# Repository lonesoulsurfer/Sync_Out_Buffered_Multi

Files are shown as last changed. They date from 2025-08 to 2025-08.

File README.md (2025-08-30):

Buffered Multiple for Modular Synths - Powered by Arduino

thumbnail_IMG_1372

Vid of the Sync in action
https://youtu.be/81T7WBMwU_8

Step by step guide (Instructables)
https://www.instructables.com/Buffered-Multiple-for-Modular-Synths-Powered-by-Ar/

Takes one sync input signal and produces six individually configurable outputs
 - Shows current BPM on OLED display
 - Each output can be configured with:
      - Normal sync (1:1)
      - Clock division (1/2, 1/4, 1/8)
      - Three groove patterns:
          - GS: Swing (delays off-beats by fixed amount)
          - GF: Shuffle (creates triplet-based rhythm)
          - GH: Humanize (adds random timing variations)

Groove Implementation 

Swing (GS) = consistent delayed off-beats
 -Delays off-beats by shifting timing up to 66% through beat
- Very classic swing feel at 50-75% intensities
- Clean implementation with consistent timing

Shuffle (GF) = polyrhythmic feel with specific timing ratios
- Creates 2-against-3 feel using weighted offset timing
- Distinct from swing - pushes toward triplet territory
- At 75%, approaches dotted 8th feeling (funkier)

Humanize (GH) = unpredictable variations
- Adds random timing variation around off-beats
- Much stronger randomization (up to 40% of beat)
- More chaotic/organic feel compared to others

The implementation provides good sonic variety between the modes. Each mode serves a distinct musical purpose, and the intensity levels (50%/75%) allow meaningful adjustment.
The two intensity levels (50% and 75%) offer enough adjustability without overcomplicating the interface. This gives users six distinct groove feels to choose from (three types × two intensities), which is a good balance for this type of device.

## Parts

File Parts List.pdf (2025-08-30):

Part Type Value Qty | Image | Link | Notes
Capacitor Polypropylene 104J 100nf 1 | | Link (https://vi.aliexpress.com/w/wholesale-capacitor-100nf.html?spm=a2g0o.productlist.search.0)
Capacitor Polarized 100uf 1 ESR | | Link (https://vi.aliexpress.com/w/wholesale-capacitor-100uf-.html?spm=a2g0o.productlist.search.0) | I like to use high frequency, low noise capacitors
Momentary (PN SKRCADD010) 3 Switch On/Off Toggle Switch Through Hole version 1 | | Link (https://www.aliexpress.com/w/wholesale-SKRCADD010.html?spm=a2g0o.productlist.search.0) Link (https://vi.aliexpress.com/item/1005001510219617.html) | Make sure that the pins on the switch are Stich pins and are able to go through the holes in the PCB
Female Header Pin Socket 15 Pin 2 | | Link (https://vi.aliexpress.com/w/wholesale-Single-Row-Female-2.54MM-Spacing-Pin.html) | These are used to hold the Arduino into place. You could solder the Arduino onto the PCB but be careful of shorts that may happen against the components on the other side
Arduino Nano 3 1 | | Link (https://vi.aliexpress.com/w/wholesale-arduino-nano.html?spm=a2g0o.detail.search.0)
Audio Socket 3.5mm (PN - PJ-301M) 7 | | Link (https://vi.aliexpress.com/item/1005005352992401.html?scm_id=1007.40050.354490.0&scm-url=1007.40050.354490.0)
Mini JST Connector and wire 2 Pin 1 | | Link (https://vi.aliexpress.com/item/1005005939956886.html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) | This is used to either power the PCB or to test it. If you are going with the 9v battery then you could leave this
LED 3mm (any colour) 1 | | Link (https://vi.aliexpress.com/w/wholesale-3mm-led-assorted.html?spm=a2g0o.productlist.search.0)
OLED Display I2C, 4 Pin 1 128X64 | | Link (https://www.aliexpress.com/w/wholesale-oled-128-x-64.html?spm=a2g0o.home.search.0)
220R Resistors Metal Film 1% 2.2K | 6 1 | | Link (https://vi.aliexpress.com/w/wholesale-resistor-metal-film.html?spm=a2g0o.productlist.search.0)

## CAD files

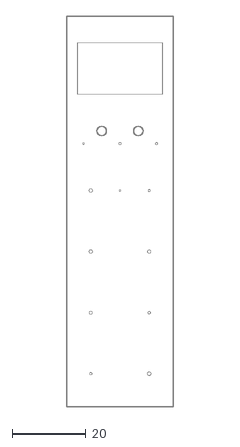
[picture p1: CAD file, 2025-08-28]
Front Panel Design/Sync Out - PCB.dxf
28.8 x 105.5

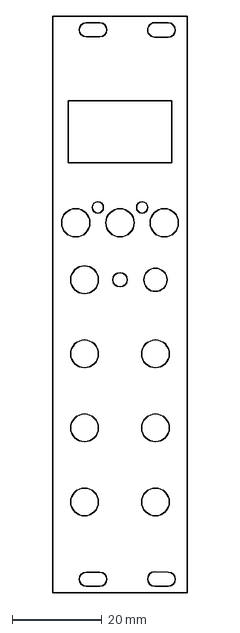
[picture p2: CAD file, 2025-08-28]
Front Panel Design/Sync Out - Fusion.dxf
30.0 x 128.5 mm

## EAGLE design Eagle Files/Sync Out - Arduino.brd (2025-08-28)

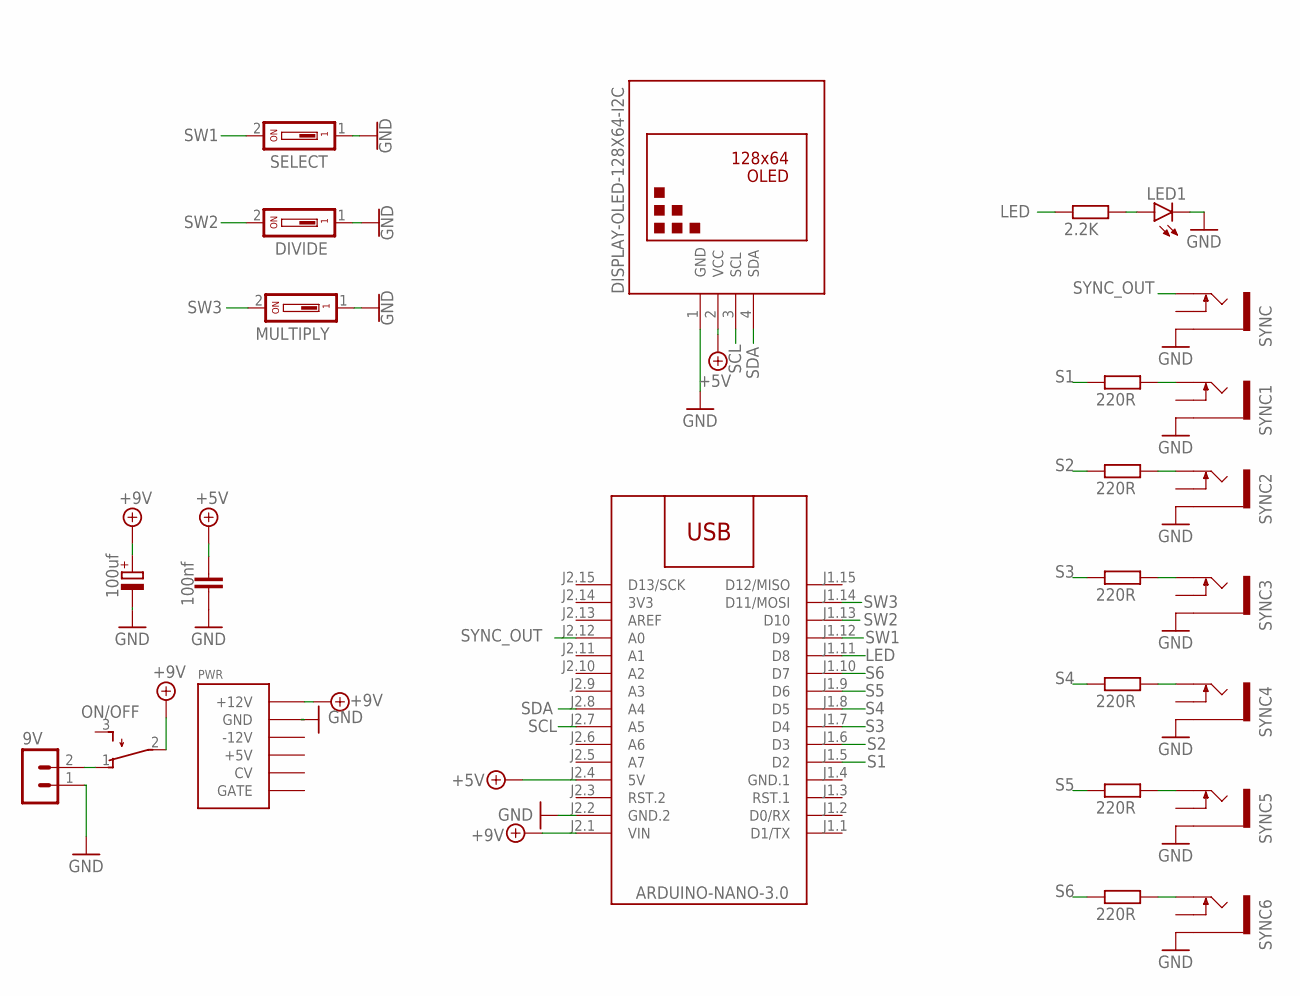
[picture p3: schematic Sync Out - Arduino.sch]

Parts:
9V: B2B-PH-K-S
C1: 100nf; C050-024X044
C3: 100uf; E2-5
DIVIDE: DS01; DS-01
LED1: LED3MM
M1: ARDUINO-NANO-3.0
MULTIPLY: DS01; DS-01
ON/OFF: TL32PO; TL3XPO
PWR: POWER; POWER_16
R1, R2, R3, R4, R5, R6: 220R; 0207/10
R7: 2.2K; 0207/10
SELECT: DS01; DS-01
SYNC, SYNC1, SYNC2, SYNC3, SYNC4, SYNC5, SYNC6: THONKICONNNEW; WQP-PJ301M-12_JACK
U$2: DISPLAY-OLED-128X64-I2C

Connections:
3V3: M1.J2.14 (3V3)
+5V: C1.1, M1.J2.4 (5V), U$2.2 (VCC)
+9V: C3.+, M1.J2.1 (VIN), ON/OFF.2, PWR.9 (+12V), PWR.10 (+12V)
GND: 9V.1, C1.2, C3.-, DIVIDE.1, LED1.K (C), M1.J2.2 (GND.2), MULTIPLY.1, PWR.3 (GND), PWR.4 (GND), PWR.5 (GND), PWR.6 (GND), PWR.7 (GND), PWR.8 (GND), SELECT.1, SYNC.P$3_SLEEVE (SLEEVE), SYNC1.P$3_SLEEVE (SLEEVE), SYNC2.P$3_SLEEVE (SLEEVE), SYNC3.P$3_SLEEVE (SLEEVE), SYNC4.P$3_SLEEVE (SLEEVE), SYNC5.P$3_SLEEVE (SLEEVE), SYNC6.P$3_SLEEVE (SLEEVE), U$2.1 (GND)
GND.1: M1.J1.4 (GND.1)
LED: M1.J1.11 (D8), R7.1
unnamed: LED1.A, R7.2
unnamed: 9V.2, ON/OFF.1 (O)
unnamed: R1.2, SYNC1.P$1_TIP (TIP)
unnamed: R2.2, SYNC2.P$1_TIP (TIP)
unnamed: R3.2, SYNC3.P$1_TIP (TIP)
unnamed: R4.2, SYNC4.P$1_TIP (TIP)
unnamed: R5.2, SYNC5.P$1_TIP (TIP)
unnamed: R6.2, SYNC6.P$1_TIP (TIP)
S1: M1.J1.5 (D2), R1.1
S2: M1.J1.6 (D3), R2.1
S3: M1.J1.7 (D4), R3.1
S4: M1.J1.8 (D5), R4.1
S5: M1.J1.9 (D6), R5.1
S6: M1.J1.10 (D7), R6.1
SCL: M1.J2.7 (A5), U$2.3 (SCL)
SDA: M1.J2.8 (A4), U$2.4 (SDA)
SW1: M1.J1.12 (D9), SELECT.2
SW2: DIVIDE.2, M1.J1.13 (D10)
SW3: M1.J1.14 (D11/MOSI), MULTIPLY.2
SYNC_OUT: M1.J2.12 (A0), SYNC.P$1_TIP (TIP)

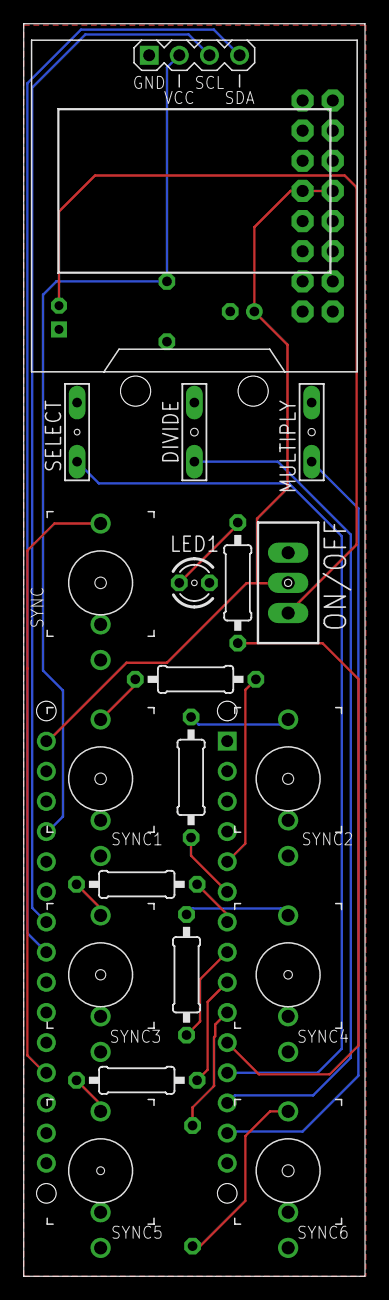
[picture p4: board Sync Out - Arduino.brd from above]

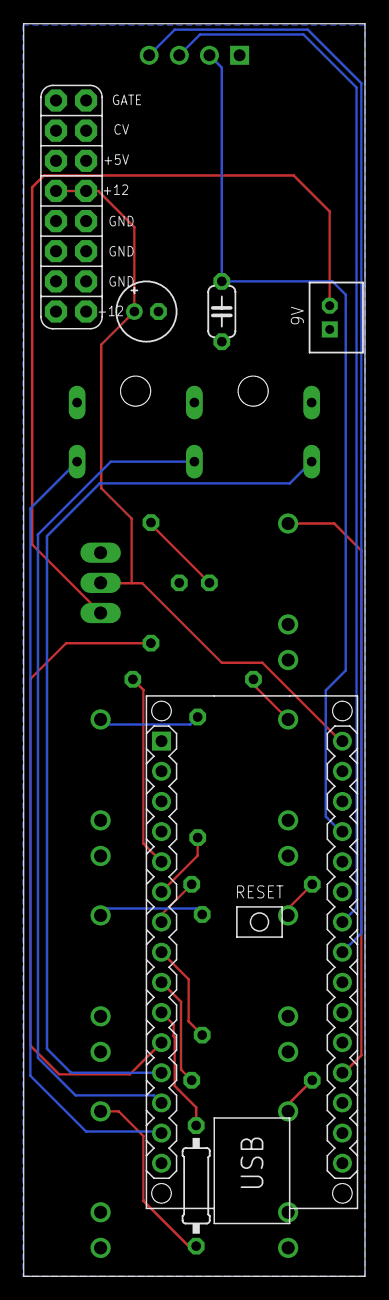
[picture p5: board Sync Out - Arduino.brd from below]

Board: 2 copper layers, 28.8 x 105.5 mm, 25 parts (6 on the bottom side), 24 nets.

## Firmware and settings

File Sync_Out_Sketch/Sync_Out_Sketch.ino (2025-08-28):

/* Synth Sync Signal Splitter with BPM display and clock division/groove
  Creates 6 buffered sync output signals from 1 input signal
  For Arduino Nano
*/

#include <Wire.h>
#include <Adafruit_GFX.h>
#include <Adafruit_SSD1306.h> // Display driver

#define SCREEN_WIDTH 128
#define SCREEN_HEIGHT 64
#define OLED_RESET -1
Adafruit_SSD1306 display(SCREEN_WIDTH, SCREEN_HEIGHT, &Wire, OLED_RESET);
// Constants for groove patterns
#define GROOVE_STRAIGHT 0    // No groove
#define GROOVE_SWING_8TH 1   // Standard swing feel
#define GROOVE_SHUFFLE 2     // Triplet-based shuffle
#define GROOVE_HUMANIZE 3    // Random humanization

// Groove settings (-8 to -1 now represent groove patterns instead of multiplication)
int grooveAmount[] = {0, 0, 0, 0, 0, 0}; // Amount of groove (0-100%)
int grooveType[] = {GROOVE_STRAIGHT, GROOVE_STRAIGHT, GROOVE_STRAIGHT, GROOVE_STRAIGHT, GROOVE_STRAIGHT, GROOVE_STRAIGHT};

const int syncInPin = A0;    // Analog input pin for sync signal
const int syncOutPins[] = {2, 3, 4, 5, 6, 7}; // Six digital output pins
const int indicatorLED = 8;  // LED to indicate sync pulses
const unsigned long minPulseWidth = 30;  // Increased pulse width for better synth compatibility
const int threshold = 400;   // Adjusted for 2V input

// Button pins
const int selectButton = 9;  // Button to select which output to adjust
const int divideButton = 10; // Button to increase division
const int multiplyButton = 11; // Button to increase multiplication

// Button states
bool lastSelectState = HIGH;
bool lastDivideState = HIGH;
bool lastMultiplyState = HIGH;
unsigned long lastDebounceTime = 0;
unsigned long debounceDelay = 50; // Debounce time in ms

// Division/groove values
// Values < 0 represent groove mode (e.g., -1 = groove active)
// Values > 0 represent division (e.g., 2 = 1/2 speed)
// Value of 1 is normal speed
int clockRatios[] = {1, 1, 1, 1, 1, 1};
int selectedOutput = 0; // Currently selected output (0-5)

// Count pulses for each output
int pulseCounts[] = {0, 0, 0, 0, 0, 0};
// Output state trackers
bool outputStates[] = {false, false, false, false, false, false};

unsigned long lastPulseTime = 0;
unsigned long currentTime = 0;
unsigned long lastDisplayUpdate = 0;
unsigned long pulseStartTime[6] = {0}; // Track when each output was turned on
float bpm = 120; // Start with default value
bool showingBpm = false;
float lastValidBpm = 0;
unsigned long bpmStableTime = 0;
bool lastSyncState = false;
unsigned long lastPulseTimeout = 2000;
unsigned long lastSubdivisionTime[6] = {0}; // Track timing for each output
unsigned long lastStableBpm = 0; // Track when we last had a stable BPM
bool bpmDisplayStable = false; // Flag to indicate if BPM is stable

// BPM averaging
#define BPM_SAMPLES 3
unsigned long pulseTimes[BPM_SAMPLES];
int pulseIndex = 0;

void setup() {
  // Set all output pins
  for (int i = 0; i < 6; i++) {
    pinMode(syncOutPins[i], OUTPUT);
    digitalWrite(syncOutPins[i], LOW);
  }
  
  // Set button pins as inputs with pull-up resistors
  pinMode(selectButton, INPUT_PULLUP);
  pinMode(divideButton, INPUT_PULLUP);
  pinMode(multiplyButton, INPUT_PULLUP);
  
  pinMode(syncInPin, INPUT);
  pinMode(indicatorLED, OUTPUT);
  
  // Initialize OLED
  if(!display.begin(SSD1306_SWITCHCAPVCC, 0x3C)) {
    for(;;);
  }
  
  display.clearDisplay();
  display.setTextSize(2);
  display.setTextColor(SSD1306_WHITE);
  display.setCursor(20, 0);
  display.println("SYNC OUT");
  display.display();
  delay(1000);
  
  // Initialize pulse time array
  for (int i = 0; i < BPM_SAMPLES; i++) {
    pulseTimes[i] = 0;
  }
}

float calculateBPM() {
  // Calculate average duration between pulses
  unsigned long totalDuration = 0;
  int validSamples = 0;
  
  // Return early if we don't have valid samples
  if (pulseTimes[0] == 0) {
    return lastValidBpm > 0 ? lastValidBpm : 0;
  }
  
  for (int i = 0; i < BPM_SAMPLES-1; i++) {
    if (pulseTimes[i] > 0 && pulseTimes[i+1] > 0) {
      totalDuration += pulseTimes[i+1] - pulseTimes[i];
      validSamples++;
    }
  }
  
  if (validSamples > 0) {
    float avgDuration = (float)totalDuration / validSamples;
    return 60000.0 / avgDuration;
  }
  
  return 0;
}

void updateDisplay() {
  display.clearDisplay();
  display.setTextSize(1);
  display.setCursor(0, 0); 
  display.println("SYNC OUT");
  
  // Show BPM
  display.setTextSize(2);
  display.setCursor(0, 12); 
  
  // Only show a BPM if we've had pulses in the last 3 seconds
  if (currentTime - lastPulseTime < 3000) {
    // Only update lastValidBpm if bpm is not zero
    if (int(lastValidBpm) > 0) {
      display.print(int(lastValidBpm));
     }
 }
  else {
    display.print("---");
  }
  display.println(" BPM");
  
  // Add more space between BPM and clock divisions
  display.setCursor(0, 34);
  
  // Show clock divisions/groove
  display.setTextSize(1); // Back to size 1 (default size)
  
  display.setTextColor(SSD1306_WHITE);
  for (int i = 0; i < 6; i++) {
    display.print(i+1);
    display.print(":");
    
    if (clockRatios[i] < 0) {
      display.print("G");
      switch(grooveType[i]) {
       case GROOVE_SWING_8TH: display.print("S"); break;  // GS = Groove Swing
        case GROOVE_SHUFFLE: display.print("F"); break;    // GF = Groove Shuffle
        case GROOVE_HUMANIZE: display.print("H"); break;   // GH = Groove Humanize
      }
      display.print(grooveAmount[i]);
      display.print("%");
    } 
    else if (clockRatios[i] == 1) {
      display.print("1:1");
    } 
    else {
      display.print("1/");
      display.print(clockRatios[i]);
    }
    
    if (i == selectedOutput) {
      display.print("*"); // Mark selected output
    }
    
    display.print(" ");
    
    // New line every 3 outputs
    if (i == 2) {
      display.setCursor(0, 46);
    }
  }
  
  display.display();
}

void handleButtons() {
  // Read button states
  bool selectState = digitalRead(selectButton);
  bool divideState = digitalRead(divideButton);
  bool multiplyState = digitalRead(multiplyButton);
  
  // Handle select button (with debounce)
  if (selectState != lastSelectState && millis() - lastDebounceTime > debounceDelay) {
    lastDebounceTime = millis();
    if (selectState == LOW) { // Button pressed
      selectedOutput = (selectedOutput + 1) % 6;
      updateDisplay();
    }
    lastSelectState = selectState;
  }
  
  // Handle divide button (with debounce)
  if (divideState != lastDivideState && millis() - lastDebounceTime > debounceDelay) {
    lastDebounceTime = millis();
    if (divideState == LOW) { // Button pressed
      // Increase division (or decrease multiplication)
      if (clockRatios[selectedOutput] < 0) {
        // Currently in groove mode
        // Go to normal
        clockRatios[selectedOutput] = 1;
        grooveAmount[selectedOutput] = 0;
        grooveType[selectedOutput] = GROOVE_STRAIGHT;
      } else if (clockRatios[selectedOutput] == 1) {
        // Currently normal, switch to division
        clockRatios[selectedOutput] = 2; // Start at 1/2 speed
      } else {
        // Already in division mode
        clockRatios[selectedOutput] *= 2; // Double division (slower)
        if (clockRatios[selectedOutput] > 64) clockRatios[selectedOutput] = 64; // Max division 1/64
      }
      updateDisplay();
    }
    lastDivideState = divideState;
  }
  
  // Handle multiply button (with debounce)
  if (multiplyState != lastMultiplyState && millis() - lastDebounceTime > debounceDelay) {
    lastDebounceTime = millis();
    if (multiplyState == LOW) { // Button pressed
      // Increase multiplication (or decrease division)
      if (clockRatios[selectedOutput] > 1) {
        // Currently in division mode
        // If we're at 1/2, go straight to normal
        if (clockRatios[selectedOutput] == 2) {
          clockRatios[selectedOutput] = 1;
          grooveType[selectedOutput] = GROOVE_STRAIGHT;
        } else {
          clockRatios[selectedOutput] /= 2; // Move closer to 1 (faster)
        }
      } else if (clockRatios[selectedOutput] == 1) {
        // Currently normal, switch to groove mode
        clockRatios[selectedOutput] = -1; // Negative values = groove
        grooveType[selectedOutput] = GROOVE_SWING_8TH;
        grooveAmount[selectedOutput] = 50; // Start with 50% swing
      } else {
        // Already in groove mode, cycle through patterns
        // Skip GROOVE_STRAIGHT (0) in the cycle to avoid those "do nothing" modes
        if (grooveType[selectedOutput] == GROOVE_SWING_8TH) {
          grooveType[selectedOutput] = GROOVE_SHUFFLE;
        } else if (grooveType[selectedOutput] == GROOVE_SHUFFLE) {
          grooveType[selectedOutput] = GROOVE_HUMANIZE;
        } else { // GROOVE_HUMANIZE or any other
          // After cycle completes, return to SWING but with increased intensity
          grooveType[selectedOutput] = GROOVE_SWING_8TH;
          grooveAmount[selectedOutput] = min(grooveAmount[selectedOutput] + 25, 100);
          if (grooveAmount[selectedOutput] > 75) {
            clockRatios[selectedOutput] = 1; // Back to normal after max groove
          }
        }
      }
      updateDisplay();
    }
    lastMultiplyState = multiplyState;
  }
}

void handleGroove() {
  unsigned long currentTime = millis();
  
  for (int i = 0; i < 6; i++) {
    // Only process if in groove mode
    if (clockRatios[i] < 0) {
      // Skip if no recent pulses or BPM too low
      if (currentTime - lastPulseTime > 2000 || bpm < 30) continue;
      
      // Get beat duration
      unsigned long beatDuration = 60000 / bpm;
      
      // Only process for outputs not already high
      if (!outputStates[i]) {
        unsigned long timeSinceMainPulse = currentTime - lastSubdivisionTime[i];
         
        // Apply groove based on type
        switch (grooveType[i]) {
          case GROOVE_SWING_8TH:
            {
         // Calculate swing timing (move off-beat later based on amount)     
              // More dramatic swing effect: up to 66% of beat duration at max intensity
              unsigned long swingTime = beatDuration/2 + 
                                      (beatDuration/3 * grooveAmount[i]/100);              
               
            // Use a wider detection window (like in humanize mode)
              if (!outputStates[i] && timeSinceMainPulse >= (swingTime - 20) && 
                  timeSinceMainPulse <= (swingTime + 20)) {    // No randomization in swing mode - always consistent timing
                outputStates[i] = true;
                digitalWrite(syncOutPins[i], HIGH);
                pulseStartTime[i] = currentTime;       
              }
            }
            break;
            
          case GROOVE_SHUFFLE:
            // Triplet-based shuffle - create pulses at 1/3 and 2/3 points
            {
           // New approach: use 2-against-3 polyrhythm for shuffle feel
              // Only fire pulses on the downbeat and one weighted offset
               
              // Effective time since the last main pulse   
              unsigned long timeSinceMainPulse = currentTime - lastSubdivisionTime[i];
               
              // Ensure we're not past the next beat
              if (timeSinceMainPulse >= beatDuration) {
                break;
              }
               
              // Instead of triplets, use a weighted offset that feels like shuffle
              // At 100% intensity, this becomes close to a dotted 8th
              // Start with base offset (halfway through beat)
              unsigned long baseOffset = beatDuration / 2;
              
              // Adjust offset based on groove intensity (0-100%)
              // This creates a continuum between straight 8ths and dotted 8ths
              unsigned long adjustedOffset = baseOffset + 
                                           (baseOffset/3 * grooveAmount[i]/100);
                                           
              // Use a wide detection window for reliable triggering
              if (timeSinceMainPulse >= (adjustedOffset - 15) && 
                  timeSinceMainPulse <= (adjustedOffset + 15) && 
                  !outputStates[i]) {
                outputStates[i] = true;
                digitalWrite(syncOutPins[i], HIGH);
                pulseStartTime[i] = currentTime;
                
                 // Extra pulse width handled by handleClockDivision()
                // Avoid delays here to prevent timing issues
              }
             }                   
            break;
            
          case GROOVE_HUMANIZE:
            // Random timing variations around the off-beat
            if (beatDuration > 0) {
              // Create pulses at half-beat points with random variation
              unsigned long halfBeat = beatDuration / 2;  
              unsigned long timeSinceMainPulse = currentTime - lastPulseTime;
               // Much stronger humanize effect: up to 40% of beat at max intensity
               int variation = map(grooveAmount[i], 0, 100, 0, beatDuration*2/5);
              
              // Check if we're near the halfway point (with tolerance)
              if (!outputStates[i] && 
               timeSinceMainPulse >= (halfBeat - 20) && 
                   timeSinceMainPulse <= (halfBeat + 20)) {
                int randomOffset = random(-variation, variation);
                // Apply the random offset to make humanize more pronounced
                // Using a much shorter delay to avoid blocking
                delayMicroseconds(abs(randomOffset) * 100);
                outputStates[i] = true;
                digitalWrite(syncOutPins[i], HIGH);
                pulseStartTime[i] = currentTime;       
              }
            }
            break;
        }
      }
    }
  }
}

void handleClockDivision() {
  currentTime = millis();

  // For shuffle (GH) mode, force a pulse if we're in triplet zone
  if (bpm > 0) {
    unsigned long beatDuration = 60000 / bpm;
    unsigned long elapsedTime = currentTime - lastPulseTime;
    
    for (int i = 0; i < 6; i++) {
      if (clockRatios[i] < 0 && grooveType[i] == GROOVE_SHUFFLE && 
          grooveAmount[i] > 0 && !outputStates[i]) {
      }
    }
  }
  // Turn off outputs that have been high long enough
  for (int i = 0; i < 6; i++) {
  // Make pulse width longer for groove modes to help sequencer detection    
unsigned long pulseWidth;
    if (clockRatios[i] < 0) {
      // Use consistent pulse width for all groove types
      pulseWidth = minPulseWidth * 5;  // Very long pulse for all groove modes
    } else {
      pulseWidth = minPulseWidth;
    }
    
    if (outputStates[i] && currentTime - pulseStartTime[i] >= pulseWidth) {
      digitalWrite(syncOutPins[i], LOW);
      outputStates[i] = false;
     
    }
  }
  
  // Check if this is a new pulse
  int syncValue = analogRead(syncInPin);
  bool syncState = (syncValue >= threshold);
  
  if (syncState && !lastSyncState) { // Rising edge detected
    // Handle BPM calculation
    pulseTimes[pulseIndex] = currentTime;
    pulseIndex = (pulseIndex + 1) % BPM_SAMPLES;

    // Calculate BPM and store valid values
    float newBpm = calculateBPM();
    if (newBpm > 30) {  // Only accept reasonable BPM values
      lastValidBpm = newBpm;
    }
    lastPulseTime = currentTime; 
    bpmStableTime = currentTime;
    showingBpm = true; // Signal that we should show BPM
    // Turn on indicator LED
    digitalWrite(indicatorLED, HIGH);
    
    // Process all outputs
    for (int i = 0; i < 6; i++) {
      // Normal speed or groove-enabled channels
      if (clockRatios[i] <= 1) {
        pulseCounts[i]++; // Count all pulses for groove patterns
        lastSubdivisionTime[i] = currentTime; // Reset subdivision timer for groove patterns
        // Output on main beat for both normal and groove modes
        if (clockRatios[i] == 1) {
          digitalWrite(syncOutPins[i], HIGH);
          outputStates[i] = true;
          pulseStartTime[i] = currentTime;
        }
      }
      // Division
      else if (clockRatios[i] > 1) {
        // Only output on specific divisions
        if (pulseCounts[i] % clockRatios[i] == 0) {
          digitalWrite(syncOutPins[i], HIGH);
          outputStates[i] = true;
          pulseStartTime[i] = currentTime;
        }
        pulseCounts[i]++;
      }
    }
  } else if (!syncState && lastSyncState) { // Falling edge detected
    // Turn off indicator LED
    digitalWrite(indicatorLED, LOW);
  }
  
  lastSyncState = syncState;
  
  // Check for timeout on sync pulses
  if (bpm > 0 && currentTime - lastPulseTime > lastPulseTimeout) {
    // If no pulses for a while, reset the BPM display 
  }
  
  // Occasionally update the display
  if (currentTime - lastDisplayUpdate >= 500) {
    lastDisplayUpdate = currentTime;
    
    // Update display with current BPM
    if (currentTime - bpmStableTime > 5000) {
      bpmDisplayStable = false;
    }
    
    updateDisplay();
  }
}

void loop() {
  // Process button presses
  handleButtons();
 
   // Process any groove patterns
   handleGroove();
  
  // Process incoming clock signal
  handleClockDivision();
}

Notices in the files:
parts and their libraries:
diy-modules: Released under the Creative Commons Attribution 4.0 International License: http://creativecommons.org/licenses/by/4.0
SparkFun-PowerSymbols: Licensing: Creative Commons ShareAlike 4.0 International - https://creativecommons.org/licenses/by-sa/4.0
